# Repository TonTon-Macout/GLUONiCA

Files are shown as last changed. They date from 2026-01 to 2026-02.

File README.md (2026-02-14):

# GLUONiCA

Часы на базе вакуумно люминесцентного дисплея GP1294AI 256X48 и ESP32 



[https://youtu.be/9DDNec8Io-I?si=lxPgc38aLBo1mTzL](https://youtu.be/9DDNec8Io-I?si=lxPgc38aLBo1mTzL)

## Возможности часов GLUONiCA
+ показывает время
  + из rtc или ntp сервера
+ веб интерфейс для настроек
  + через браузер
  + приложение для [windows](https://github.com/TonTon-Macout/Remote-Settings-Manager) 
  + приложение для [android](https://github.com/TonTon-Macout/Remote-Settings-Manager/blob/main/android/README.md)
  + так же подойдут приложения для [Settings AlexGyver'a](https://github.com/GyverLibs/Settings) 
+ циферблаты с переключаемой информационной частью
+ выводит
  + температуру/влажность/СО2/давление
  + погоду используя сервис openweathermap.org
  + детектор грозы - AS3935 - нужно тестировать
+ показатели состояния пк (температура/загрузка итп)
+ будильник 100+ мелодий
+ кукушка
+ тихий режим - отключение всех шумных функций, снижение яркости по расписанию
+ есть возможно получать данные температуры/влажности/С02/пм с домашнего сервера mqtt (нужен home assistant)
+ в разработке

## Необходимые компоненты

на 2к26 год, приблизительная оценочная стоимость всех компонентов ~7к+ рублей без дорогих датчиков(SCD40, AS3935) и самостоятельной печатью корпуса

прошивка в разработке, поэтому пока не выкладываю, если собрали пора прошить пишите в иссусе или телегу 

ссылки на компоненты - ориентировочные, не реферальные, большая часть - первые попавшиеся

| Компонент | Кол-во | Модель | Примечание |
|---|---|---|---|
| Дисплей | 1 | GP1294AI 256X48 |  [али](https://aliexpress.ru/item/1005008543990730.html) |
| Микроконтроллер | 1 | ESP32 wroom (16мб флеш) | [ESP32-WROOM-32UE-N16](https://aliexpress.ru/item/1005002515949841.htm) + антенна |
| Датчик температуры и влажности | 1 | SHT40 / SHT30 / SHT20 |  [али](https://aliexpress.ru/item/1005010151069117.html) |
| Модуль часов | 1 | DS3231 mini |  [али](https://aliexpress.ru/item/1005008498420397.html?shpMethod=CAINIAO_STANDARD&sku_id=12000047745050119) |
| Пассивная пьезо-пищалка | 1 | 5v | |
| Датчик CO2 | 1 | SCD40 | |
| Детектор грозы | 1 | AS3935 | [али](https://aliexpress.ru/item/4001145161231.html) |
| Резистор  1206 | 6 | 10 кОм | |
| Резистор  1206 | 2 | 4.7 кОм (pull-up для I²C) | |
| Резистор  1206 | 6 | 1 кОм | |
| LED 1206 | 2 | | |
| Конденсатор керамический  1206 | 2 | 0.1 мкФ | |
| Конденсатор керамический  1206 | 1 | 0.1 мкФ | |
| Конденсатор танталовый | 2 | 22Uf 16V+ тип D или С | [чип и дип](https://www.chipdip.ru/product/tecap-22mkf-16v-tip-c-10-293d226x9016c2te3-vishay-9001567651) |
| Конденсатор танталовый | 1 | 100Uf 16V+ тип D или С | емкость не принципиальна, можно на край 22uF из прошлого пункта |
| Конденсатор электролитический | 1 | 400-1000 мкф  (между контактами 3.5мм, диаметр 8мм) |  [чип-дип](https://www.chipdip.ru/product/k50-35-470mkf-16v-105-c-20-8x12mm-p-3.5mm-jb-capacitors-9000565914) |
| Кнопки | 5 | B3F-4055 |  [али](https://aliexpress.ru/item/32827460019.html?sku_id=65007257280) |
| Крышки для кнопок | 5 | для B3F-4055  без ободка | |
| Подстроечный резистор | 1 |  0-...ом 3296 |  для подстройки громкости [али](https://aliexpress.ru/item/1005007455422471.html) | 
| Коннекторы | | шаг контактов 2.54\ кол-во контактов 2p, 4p, 5p, 6p, 8p  | |
| Провод питания дисплея | 1 | 2x0.5 - 30см | |
| Гребенка | 1 | шаг 2.54, 5pin - Для rtc + 13pin - дисплей | [али](https://aliexpress.ru/item/32847589488.html) |
| Разъем питания DC-005 | 1 |  2.1/2.5 - зависит от блока питания | |
| Клемник на плату винтовой | 1 | 2pin шаг контактов 5мм | |
| Тактовые кнопки SMD | 2 | 4X4X3.0mm 4Pin |  [али](https://aliexpress.ru/item/4001317902663.htm) |
| Предохранитель | 1 |  1,5-2 Ампер | можно любой выводной, главное чтобы подошел по размеру, я использую с разъмом размер -  MINI  [али](https://aliexpress.ru/item/4000583944011.html?sku_id=12000032327384411)  |
| Преобразователь напряжения | 1 |  AMS1117 3.3 | |
| Оптопара | 1 |  PCF817 | |
| Транзистор | 2 |  2n2222 | |
| Диод SMA | 1 |  M7 | |
| Вентилятор 5v | 1 |  2510 | |
| PCB плата | 1 | | |
| Печатные детали корпуса | | | |
| Источник питания | 1 | 5В 3A (можно 2 но лучше 3) | |
| Крепежные винты | | M1.4 6mm  острые | [али](https://aliexpress.ru/item/1005007060468439.html) |

## 💰 Если хочется сэкономить 
Я проектировал часы, так чтобы было удобно и покрасоте.
Часы приобретают более заводской вид, но это же приводит к некоторму перерасходу средств, особенно если хочется собрать только одно устройство. 

В связи с чем есть просртрансво для экономии. Часы будут выглядеть более колхозно, но кто будет заглядывать им в кишки? ) 

| Обязательные компоненты | Комментарий |
|---|--- |
| Дисплей | как можно догадаться без него не обойтись, именно тот что на фото, другой не подойдет, самая дорогая запчасть|
| Плата | тоже очевидная обязательная запчасть |
| Печатный корпус | нужен, но не строго обязательно |
| Блок питания | часы потребляют до 1 ампера тока, но блок питания рекомедую 5v3a, да с запасом но китайские амперы всегда стоит делить на два. можно 2 ампера но будет заметно греться |
|---------|------------|
| esp32  | только wroom(предпочтительней) или wrover  модули на 16 мб флеша, S3 и подобные не подойдут (другая распиновка), на 4-8 мб тоже не подходят. Я используя с внешней антенной, но с встроенной тоже подходит, место под антену есть, как будет ловить хз|
| стабилизатор 3.3v| ams1117 3.3 вольт - обязателен |
| конденсаторы | все конденсаторы служат для сглаждивания питания, строго обязателен только один - танталовый на выходе ams1117 емкостью 22uF |
| резисторы 10ком | строго-обязательные, для подтяжек кнопок, номинал 10ком приблизительный, можно +- 5ком |
| резисторы 4.7ком | строго-обязательные, для подтяжки i2c шины, номинал на крайняк можно тот же что и на подтяжки кнопок |
| резисторы 1ком | для транизосторов и оптопары , есть бузер и вентилятор - нужны. токоограничивающие для светодиодов, только если есть диоды |
| кнопки |  B3F-4055 - обязателны, колпачки можно напечатать (файла нет) |
| кнопки |  Кнопки резет и бут - опциональны, удобней прошивать но можно и без них, только замыкать для прошивки придеться пинцетом |
| раземы | DC - для блока питания обязателен, все остальные для удобства, можно паять провода прямо на плату. Да некрасиво но зато дешевле. |
| бузер  | вместо пассивного бузера может подойти любой маленький динамик от старой игрушки |
| подстроечный резистор | 50/50 - удобно регулировать громкость, но можно и просто кинуть перемычку или подобрать постоянный резистор |
| вентилятор | если ставим датчики то вентилятор нужен, без него температура на датчике улетит в космос, экран - неплохая грелка |
| диод | sma M7 есть вентилятор - нужен и диод |
| транзисторы | 2n2222 выводной для бузера и вентилятора, нужны |
| оптопара | есть вентилятор - нужна и оптопара |
| датчики | опционально, но хотябы bme 280 на 3.3 вольта |
| rtc | модуль точного времени, вообще при наличии интернета можно и без него, но с ним надежней |
| провод питания дисплея| две жилы, дисплей - основной потребитель, чем толще тем лучше, 0.5 квадрата 2 жилы должен подойти, или около того. стандартные тоненькие ардуиновские провода не подходят |
| предохранитель | желателен, можно обычный плавкий с выводами или выводы к нему припаять самостоятельно. номинал 1-2 ампера. |
| вроде ничего не забыл ||

## Дополнительно
| Компонент | Кол-во |
|---|---|
| Паяльник | 1 | 
| Припой | 1 |
| Флюс | 1 |
| 3D принтер | 1 |
| Аккуратность | ∞ |

Дисплей
------------
Снимок экрана 2026-01-25 101837
Снимок экрана 2026-01-25 101844

Корпус
------------
7a22f757-f263-40fc-9eb5-331b80968ea5

vfd_clock_futaba_gp1160a02a

Плата
--------------
Снимок экрана 2026-01-24 234943

Снимок экрана 2026-02-14 095538

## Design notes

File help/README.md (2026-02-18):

## Настройка часов GLUONiCA

- [Первоначальная настройка](https://github.com/TonTon-Macout/GLUONiCA/blob/main/help/first_start.md)

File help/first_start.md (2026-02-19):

# 🚀 Первоначальная настройка часов GLUONiCA

> 🎉 Похоже ты стал обладателем уникальных электронных часов, поздравляю!

## Для корректной работы устройства необходимо выполнить первичную настройку. Следуй пошаговой инструкции ниже.

Оглавление 
- [питание  ↓](#power)
- [wifi  ↓](#wifi)
- [вход в настройки  ↓](#enter)
- [настройки  ↓](#settings)
- [получение API ключа OpenWeatherMap  ↓](#owm)

------------
<h2 id="power" >📦 Шаг 1: Питание</h2>

Подключите часы к блоку питания (БП) с подойдет на **5V / 3A** и разъемом DC. 2А можно, но не желательно. 

<h2 id="wifi" >🌐 Шаг 2: Подключение к Wi-Fi</h2>

При первом включении часы не найдут сохраненной Wi-Fi сети и автоматически создадут собственную точку доступа.

1.  **Подключитесь к точке доступа часов:**
    *   На телефоне откройте список Wi-Fi сетей.
    *   Найдите сеть с именем ваших часов (например, `GLUONiCA_...`).
    *   *Важно:* Если ваш телефон подключен к домашнему Wi-Fi, отключитесь от него вручную, чтобы устройство гарантированно подключилось к часам и не переключалось обратно.
2.  **Настройка подключения:**
    *   После подключения к точке доступа часов автоматически должен открыться браузер с веб-интерфейсом.
    *   В открывшемся веб интерфейсе укажите:
        *   **Имя вашей домашней Wi-Fi сети** (SSID).
        *   **Пароль от Wi-Fi**.
        *   В поле **"Запуск точки доступа"** выберите режим: **`при отсутствии сети, с паролем`**.
        *   При заполнении пароля Wi-Fi сети, если он длинее 8 символов и пароль от точки дуступа не установлен, этот же пароль применится к точке доступа. При необходимости измените его. Пароль от точки доступа показывается на экране, когда запущена точка доступа!
3.  Нажмите кнопку "подключиться", если данные верны, часы подключатся к указанной WiFi сети.

<h2 id="enter" >🖥️ Шаг 3: Вход в панель управления</h2>

После подключения часов к вашей Wi-Fi сети.

1.  Нажмите на корпусе часов кнопку **"Настройки"** (обычно вторая слева) или перейдите ко второму пункту если настройки уже открыты.
2.  В правой части дисплея отобразится IP-адрес часов в локальной сети (например, `192.168.1.15`). 
      - Если там отображается надопись "Часы запущены в режиме точки доступа", значит подключение к WiFi сети не удалось, повторите шаг 2 заново. 
3.  Подключитесь к той же Wi-Fi сети со своего компьютера или телефона.
4.  Откройте браузер и введите полученный IP-адрес в адресную строку.
5.  Если у вас есть приложение, то просканируйте Wi-Fi сеть.

<h2 id="settings" >⚙️ Шаг 4: Базовая конфигурация</h2>
Вы попали в веб-интерфейс настроек. Выполните следующие действия:

### 🌦️ Настройка погоды
1.  Перейдите в раздел настроек погоды.
2.  Введите **API ключ** сервиса OpenWeatherMap (инструкция по получению — в конце).
3.  Укажите **название города**. Используйте латиницу (например, `Moscow`, `London`, `Port-aux-Français`). Для городов с дефисом или сложным именем уточняйте написание через сайт OpenWeatherMap.

### 🧰 Настройка датчиков
*Конфигурация зависит от того, какие датчики установлены в вашей модели часов.*

1.  Перейдите в раздел **"Датчики"**.
2.  **Включение датчиков:**
    *   Активируйте только те датчики, которые физически присутствуют в устройстве.
    *   Если датчик исправен и инициализировался, рядом с его названием загорится зелёный индикатор (🟢).
3.  **Назначьте источники данных:**
    *   Для каждого типа измерений (Температура, Влажность, Давление и тд) выберите конкретный датчик-источник из выпадающего списка.
    *   *Пример:* Для "Температура" можно выбрать `bme280`, `sht`, для CO2 - `SCD40`  и т.д.
4.  **Часы реального времени (RTC):**
    *   Если у вас установлен модуль DS3231, обязательно включите опцию **"DS3231"**. Это позволит часам получать время, даже при отсуствии интернета.
5.  **Адреса на шине (для опытных):**
    *   Если датчики не определяются (например вы добавили новые), проверьте и при необходимости укажите их I2C-адреса вручную. Адреса всех поключенных датчиков пишутся в лог при инициализации i2c.

### 🐞 Шаг 5: Режим отладки (Опционально)
В самом низу страницы настроек найдите раздел **Дебаг**.
*   Рекомендуется переключить режим на **`Logger`**.
*   Уровень (`Level`) можно выставить в **`Warning`** или `Error`, чтобы логи не засоряли экран, но критичные ошибки были видны, или оставить как есть.

## ✅ Шаг 6: Финал

1. Для выхода из настроек в часах, нажмите кнопку смены циферблата (обычно крайняя правая)
2. Смена информации в циферблате - кнопка инфо (обычно вторая справа)
3. Зайти в настройки - (обычно вторая слева). Для перемещения курсора - кнопки вверх и вниз (обычно первая и третья) а выбор пункта - кнопка настройки.
4. Назначение кнопок можно поменять в настройках.
<br>
Поздравляем! Если всё сделано верно, часы синхронизируют время, загрузят погоду и начнут полноценную работу. 🎉<br><br>

> 🎮 Незабудьте сыграть в игру - Злой Удав, и поделиться своим рекордом!

<br><br><br>
---

<h2 id="owm" >🔑 Получение API ключа OpenWeatherMap</h2>

Для работы погоды необходим бесплатный ключ доступа.<br>Для доступа к сайту возможно понадобится ВПН. (только для регистрации и получения ключа) 

1.  Перейдите на сайт: [https://openweathermap.org/](https://openweathermap.org/)
2.  Нажмите кнопку **"Login"**
3.  Создайте аккаунт, подтвердите email.
4.  В личном кабинете перейдите в раздел **"API Keys"** (обычно доступен по ссылке: [https://home.openweathermap.org/api_keys](https://home.openweathermap.org/api_keys)).
5.  В поле **"Create Key"** введите любое название (например, `gluonica_clock`) и нажмите **"Generate"**.
6.  В таблице отобразится новый ключ (набор букв и цифр).
    *   *Важно:* Новый ключ активируется в течение 10–30 минут.
    *   Бесплатный тариф позволяет делать до 60 запросов в минуту, чего с запасом хватает для часов, они обновляют погоду раз в 5 минут. Но если у вас ни одни часы, лучше создавать свой апи ключ для каждых. 

### 🌍 Где взять название города?
API OpenWeatherMap понимает английские названия.
*   **Для городов России:** используйте `Moscow`, `Ust’-Ordynskiy` и тп.
*   Для поиска сложных названий лучше всего найти его в файле json, скачав архив с сайта [https://bulk.openweathermap.org/sample/](https://bulk.openweathermap.org/sample/) (верхний), распокавав его и открыв файл city.list.json в блокноте, нати название своего города (учитывайте страну, должна быть RU)

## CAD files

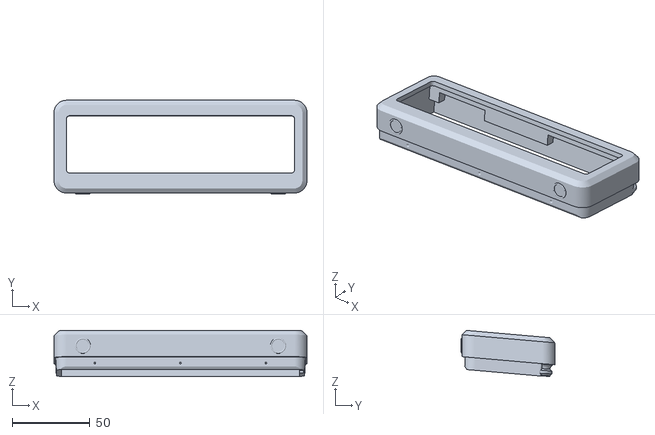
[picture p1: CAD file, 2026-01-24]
stl/mini-shorty-face.stl
163.0 x 60.2 x 29.8

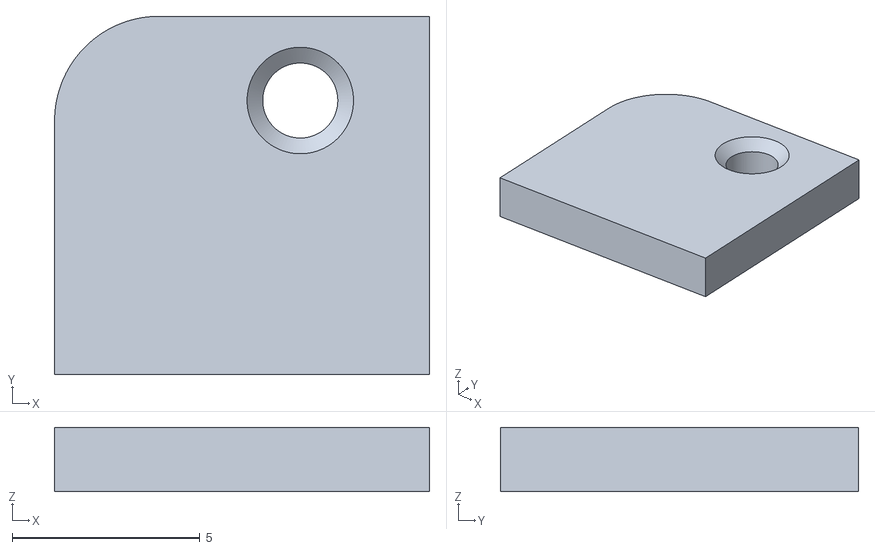
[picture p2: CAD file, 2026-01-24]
stl/pot_holder.stl
10.0 x 9.56 x 1.71

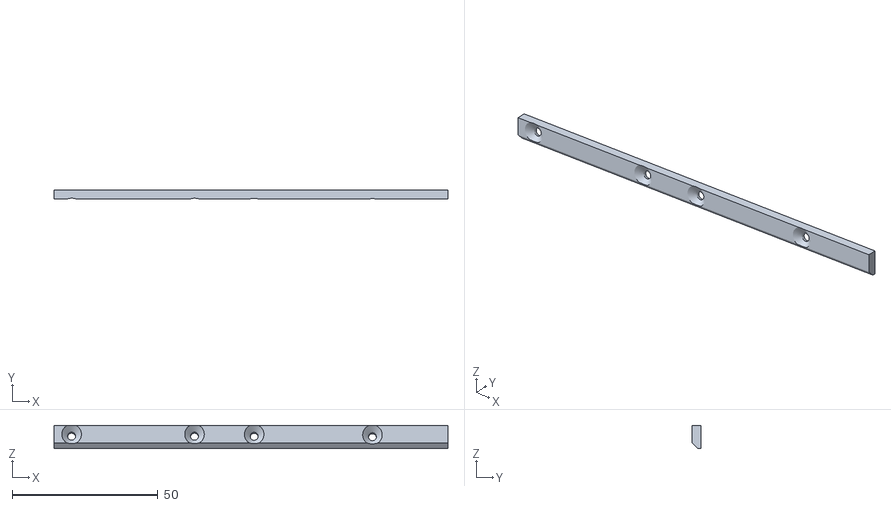
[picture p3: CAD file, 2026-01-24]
stl/buttonholder.stl
135.3 x 3.02 x 8.05

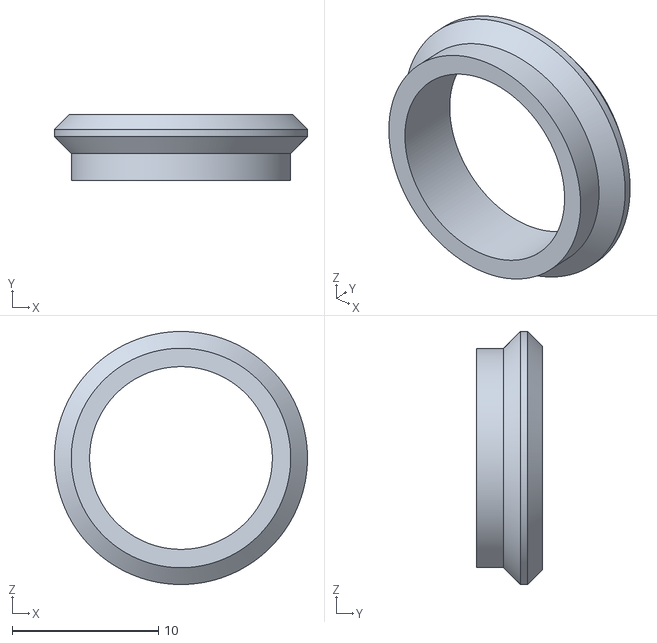
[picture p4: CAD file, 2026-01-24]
stl/button cup .stl
17.3 x 4.49 x 17.3

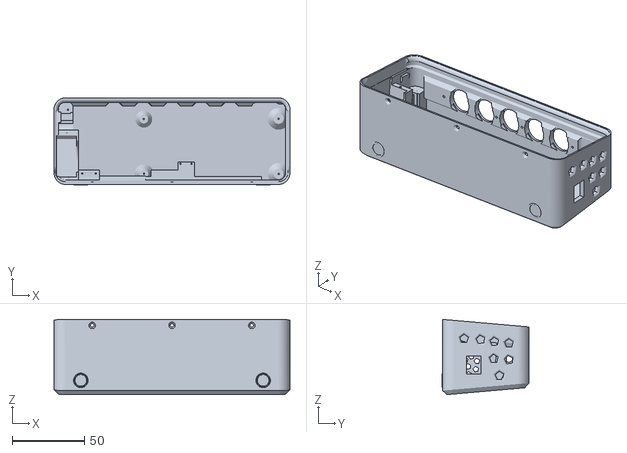
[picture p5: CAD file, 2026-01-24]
stl/mini-shorty-body.stl
163.0 x 60.2 x 52.0

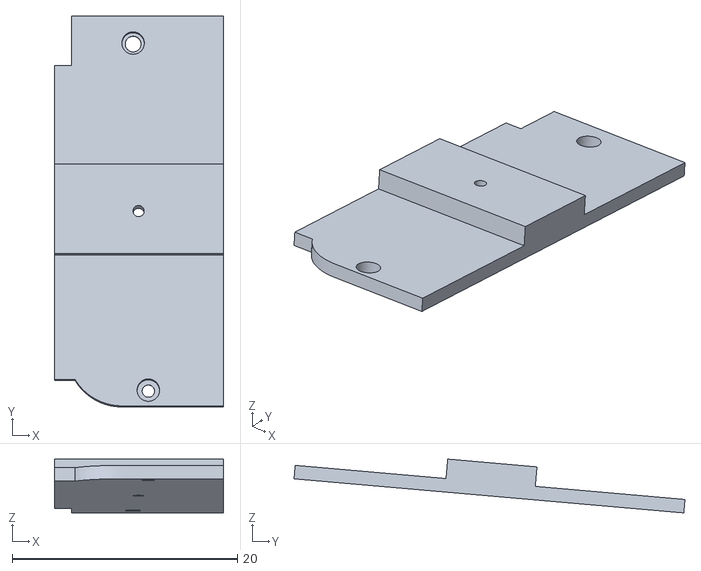
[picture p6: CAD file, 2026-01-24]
stl/fun-cap.stl
15.0 x 34.7 x 4.78

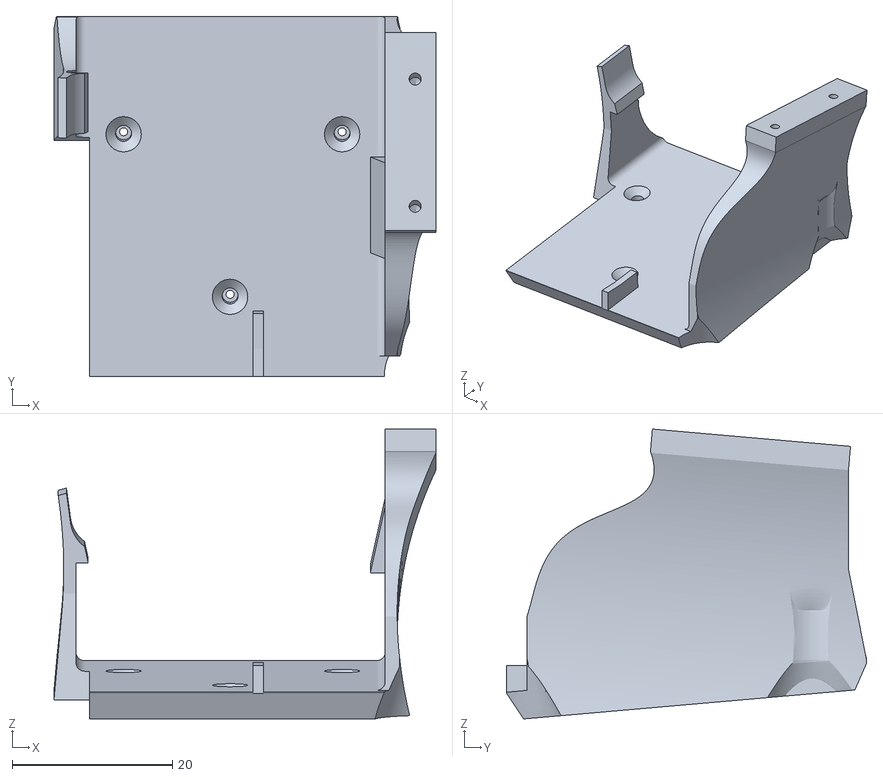
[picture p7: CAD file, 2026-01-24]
stl/innards-holder.stl
47.7 x 45.0 x 36.2

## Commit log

2026-01-24 Update resistor quantity and add LED entry
2026-02-13 Update instruction for initial device setup
2026-02-14 Fix typo in resistor description in README.md
2026-02-14 Добавить README для настройки часов GLUONiCA
    Добавлено руководство по первоначальной настройке часов GLUONiCA, включая инструкции по подключению к Wi-Fi и настройке API ключа.
2026-02-18 Revise first start guide for clarity and details
    Updated instructions for Wi-Fi connection and sensor setup.
